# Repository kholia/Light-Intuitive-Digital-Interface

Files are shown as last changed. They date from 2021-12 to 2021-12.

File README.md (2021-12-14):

#### LiDi

LiDi is Light-Intuitive-Digital-Audio-Interface for µBITX and other radios. It
is meant to be homebrewed on a `Zero PCB` in under 30 minutes.

Design 2:

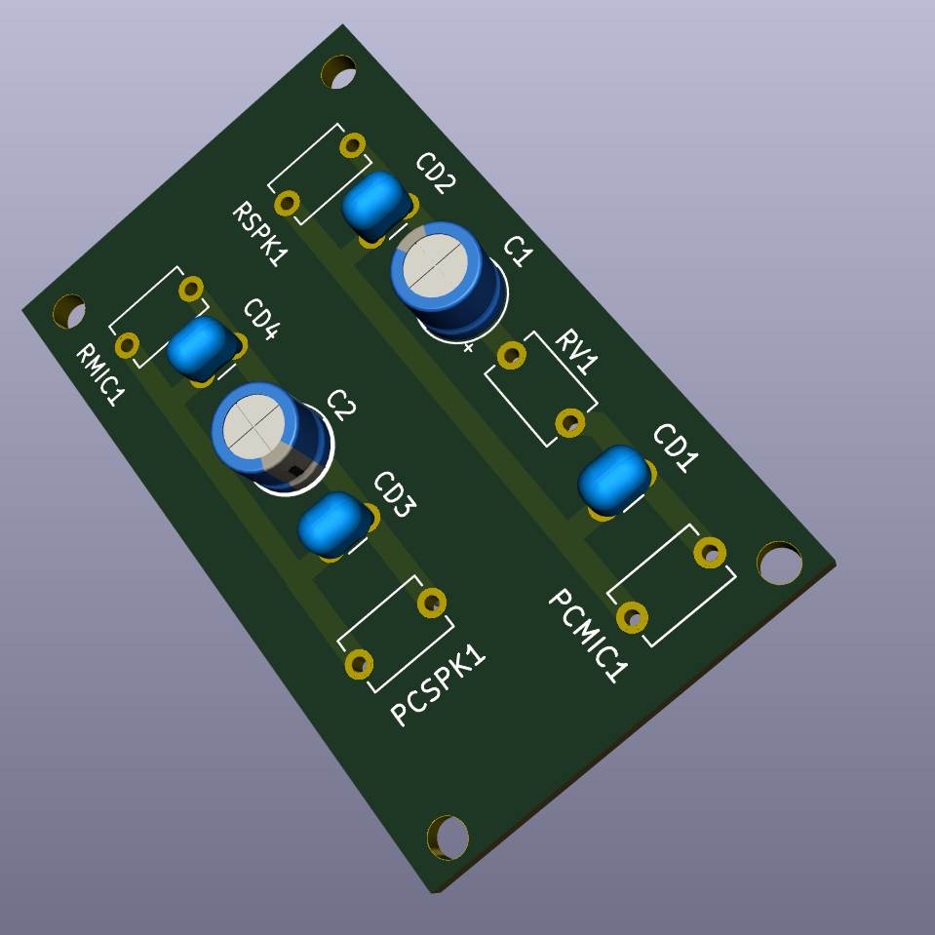
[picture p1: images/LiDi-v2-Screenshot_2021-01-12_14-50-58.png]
LiDi-v2

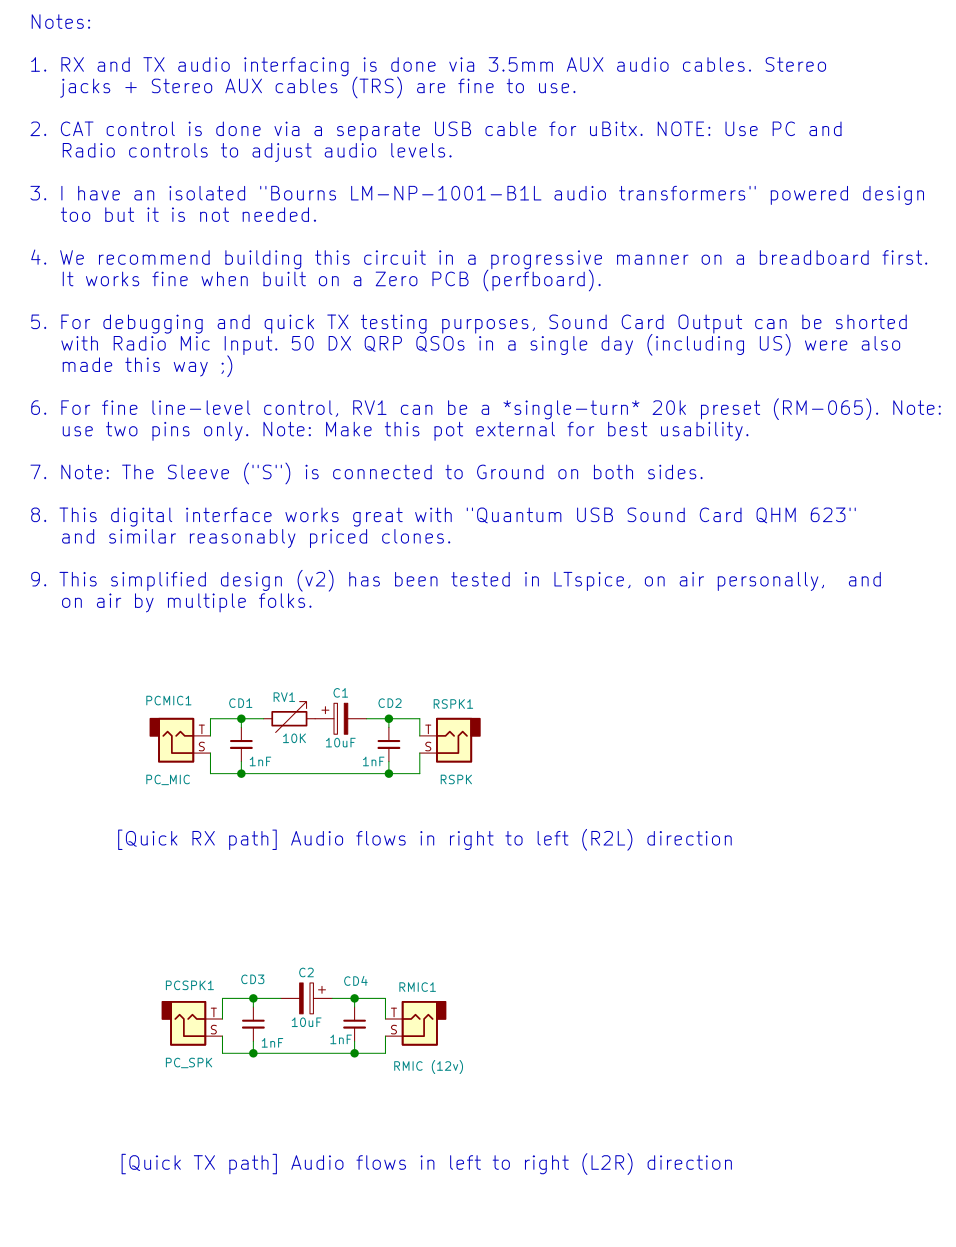
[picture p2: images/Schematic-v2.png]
LiDi-v2 Schematic


Design 1:

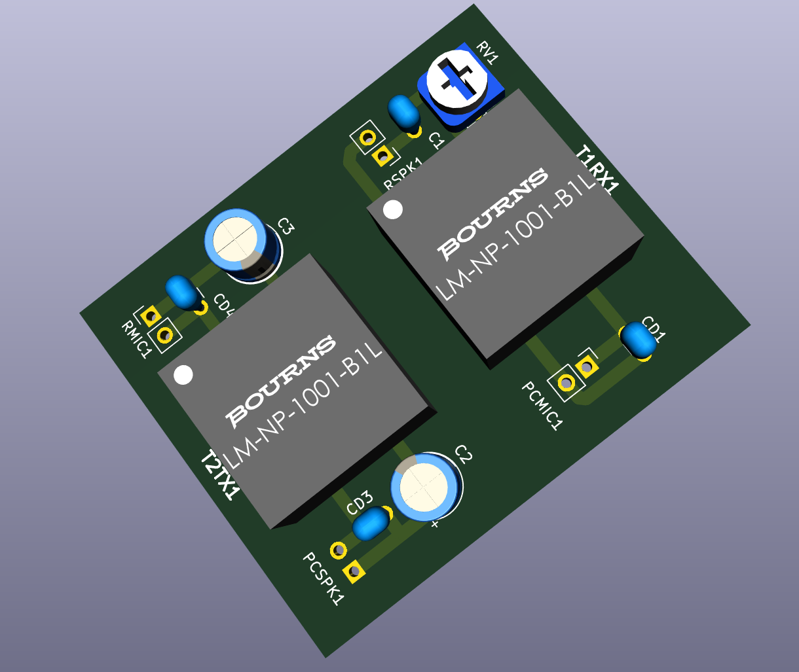
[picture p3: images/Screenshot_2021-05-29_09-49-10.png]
LiDi-v1


LiDi-v2

Full Setup 1

Note: All the included designs (and some other ones) were simulated in LTspice,
and then tested on air.

Sample testing setup on a breadboard ;)

PoC Setup 1

Sometimes, a quick shorted digital interface is all you need for a US QSO in
"Solar Minimum" conditions ;)

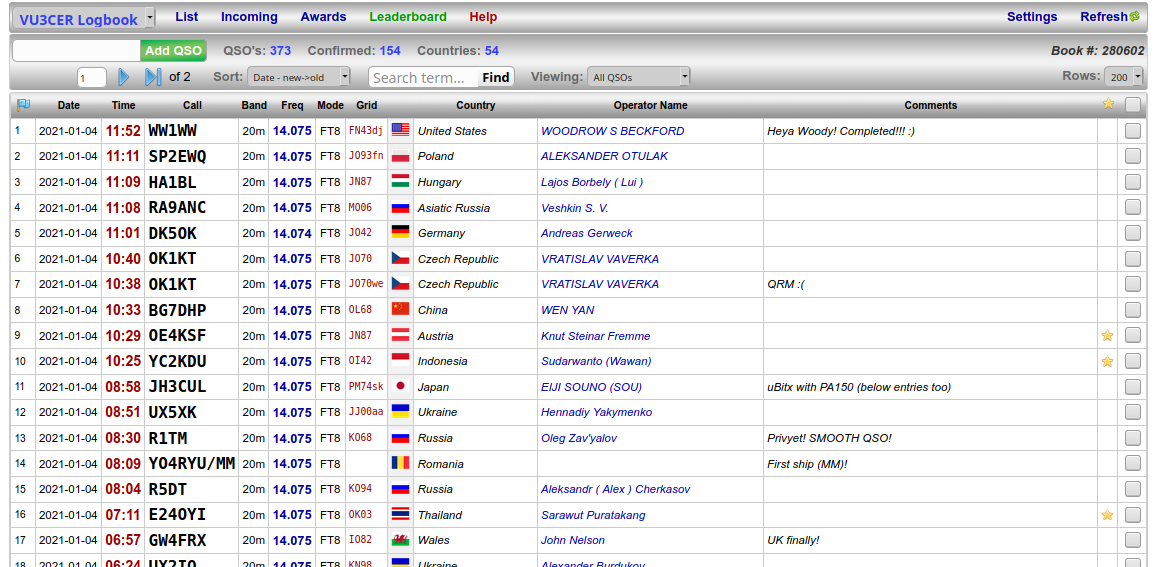
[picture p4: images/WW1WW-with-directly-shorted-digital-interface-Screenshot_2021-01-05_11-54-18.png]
Shorted-Digital-Interface


RX performance is lovely with LiDi - US @ -4.

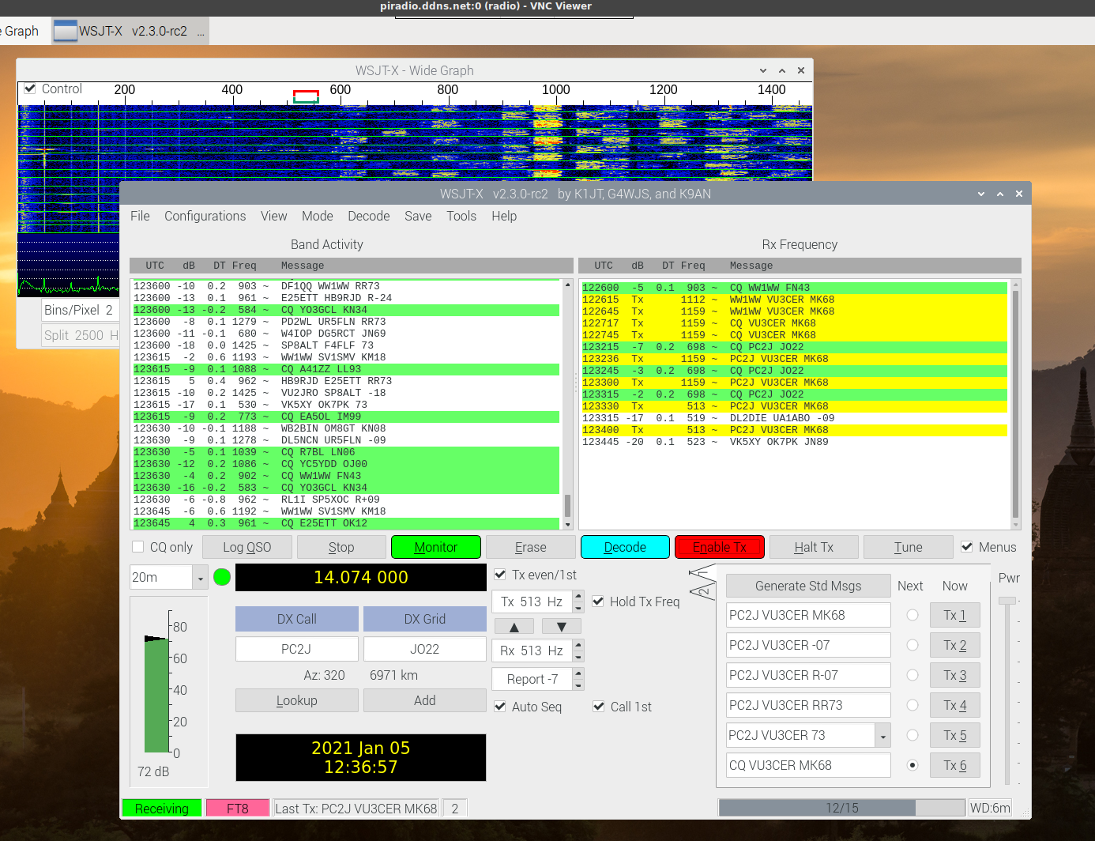
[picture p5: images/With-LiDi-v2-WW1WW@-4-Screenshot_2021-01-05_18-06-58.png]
US @ -4


50 QSOs were done with LiDi designs in a single day!

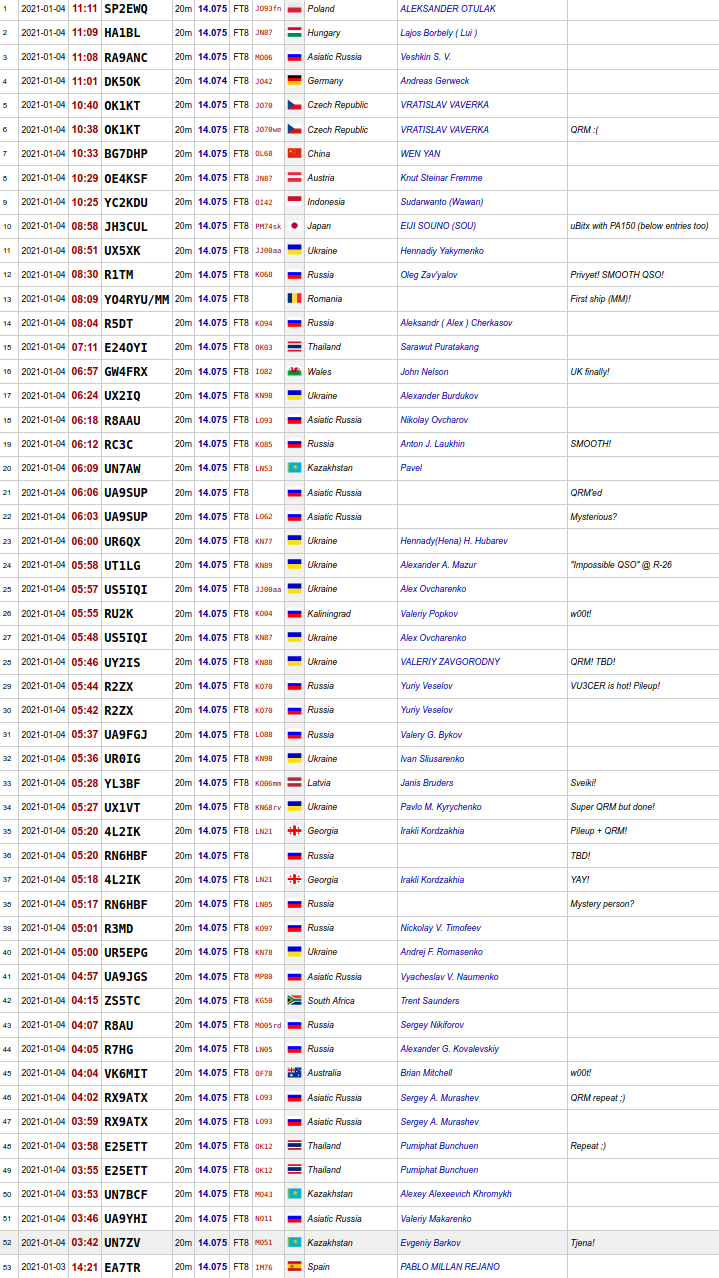
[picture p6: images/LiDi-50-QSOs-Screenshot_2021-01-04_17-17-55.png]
50 QSOs with LiDi


#### BOM Sources

- [Bourns LM-NP-1001-B1L 600:600 audio transformer](https://in.rsdelivers.com/product/bourns/lm-np-1001-b1l/chassis-mount-audio-transformer/1728110)

- [Bourns LM-NP-1001-B1L 600:600 audio transformer (alt source)](https://www.semikart.com/product/bourns-/LM-NP-1001-B1L/58614)

- [Audio & Signal isolation transformer 600:600 (alt source)](https://www.sunrom.com/p/audio-signal-isolation-transformer-600600)

- [GX-16 4-Pin Metal Aviation Plug Female](https://robu.in/product/gx-16-4-pin-metal-aviation-plug-male-and-female-panel-connector/)

- https://projectpoint.in/ (capacitors, pots, connectors)

- https://www.sunrom.com/ (audio connectors, caps, misc)

- https://www.electronicscomp.com/ (connectors, misc)

- https://www.electroncomponents.com/ (connectors, audio cables, misc)

- https://www.diyaudiocart.com/ (nice quality caps)

- [USB Sound Card](https://robu.in/product/5-1-channel-usb-sound-card-for-raspberry-pi-and-computers/)

#### µBITX Aviation Connector Pinout

Clockwise from the notch on the GX-16 connector:

Black + Blue -> Ground

Brown + "Red" -> Speaker

Anti-clockwise from the notch:

Purple -> Mic (TIP)

Orange -> PTT

Brown + "Red" -> Speaker

https://www.hfsignals.com/index.php/ubitx-wire-up/

https://source.android.com/devices/accessories/headset/plug-headset-spec

#### Tips

- Use KD8CEC firmware for µBITX. Use https://github.com/reedbn/ubitxv6 for
  µBITX v6.

- Configure WSJT-X for µBITX using details from the following article.

  http://www.hamskey.com/2018/01/wjst-x-configuration-for-ubitx.html

- For BITX40, use a suitable firmware from https://github.com/amunters.

  I have no experience with BITX40 though.

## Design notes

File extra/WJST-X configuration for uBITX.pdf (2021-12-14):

hamskey.com

## WJST-X configuration for uBITX

Share

2-3 minutes

WJST-X configuration for uBITX

Use CEC version firmware 2.5 or later of uBITX.
The following examples are based on version 0.27.
We will post the 0.27 version as the test ends.
All of the examples below only describe connections to uBITX. Please refer to the manual or other documents for how to use the program.

WJST-X
Download : https://physics.princeton.edu/pulsar/k1jt/wsjtx.html

After installing the program, connect the uBITX USB to the computer.

Run WSJT-X

Click File -> Settings...

WJST-X configuration for uBITX | about:reader?url=http://www.hamskey.com/2018/01/wj...
1 of 6 | 5/29/21, 10:24

Select Yaesu FT-817 from the Rig selection menu.

Select the serial port to which uBITX is connected.

When uBITX is connected to the USB port of the computer, the virtual serial port appears in the control panel.

The baud rate is set to 38400.

PTT Method selects CAT.

Please make other settings as shown below.

Then press the Test CAT button.
Maybe there is a timeout error.
Raduino (problem of Arduino) has the problem that it is automatically reset when first serial port is connected after power is supplied.
I've posted a troubleshooting article on my blog. If you want to solve it, please read it.

But I just use it. There will be no problem after that.

Press the Test PTT Button

Then, Your uBITX should be changed to TX mode as shown below.

Press the OK button.

The frequency of the main screen of wsjt-x may be changed automatically.
I selected the JT-65 mode and the frequency was automatically changed to 14.076.000.

Now you can have a happy ham life with wsjt-x and uBITX.

If you select a band on wsjt-x, your uBITX will automatically change its frequency and mode.
It is important. If only PTT is connected without frequency synchronization, wsjt-x may be recorded as an incorrect band when it records the log automatically.

The photo below was taken directly from this document.

The settings in the raspberry pie are the same.
The video below is a video that I tested on Windows and Raspberry.

73

Ian KD8CEC

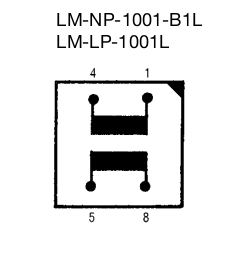
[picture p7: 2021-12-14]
images/Bourns Audio Transformer Pinout (BOTTOM VIEW IMPORTANT).png

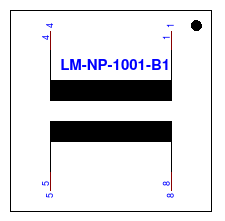
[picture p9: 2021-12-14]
images/Bourns Audio Transformer Pinout (BOTTOM VIEW IMPORTANT) 2.png

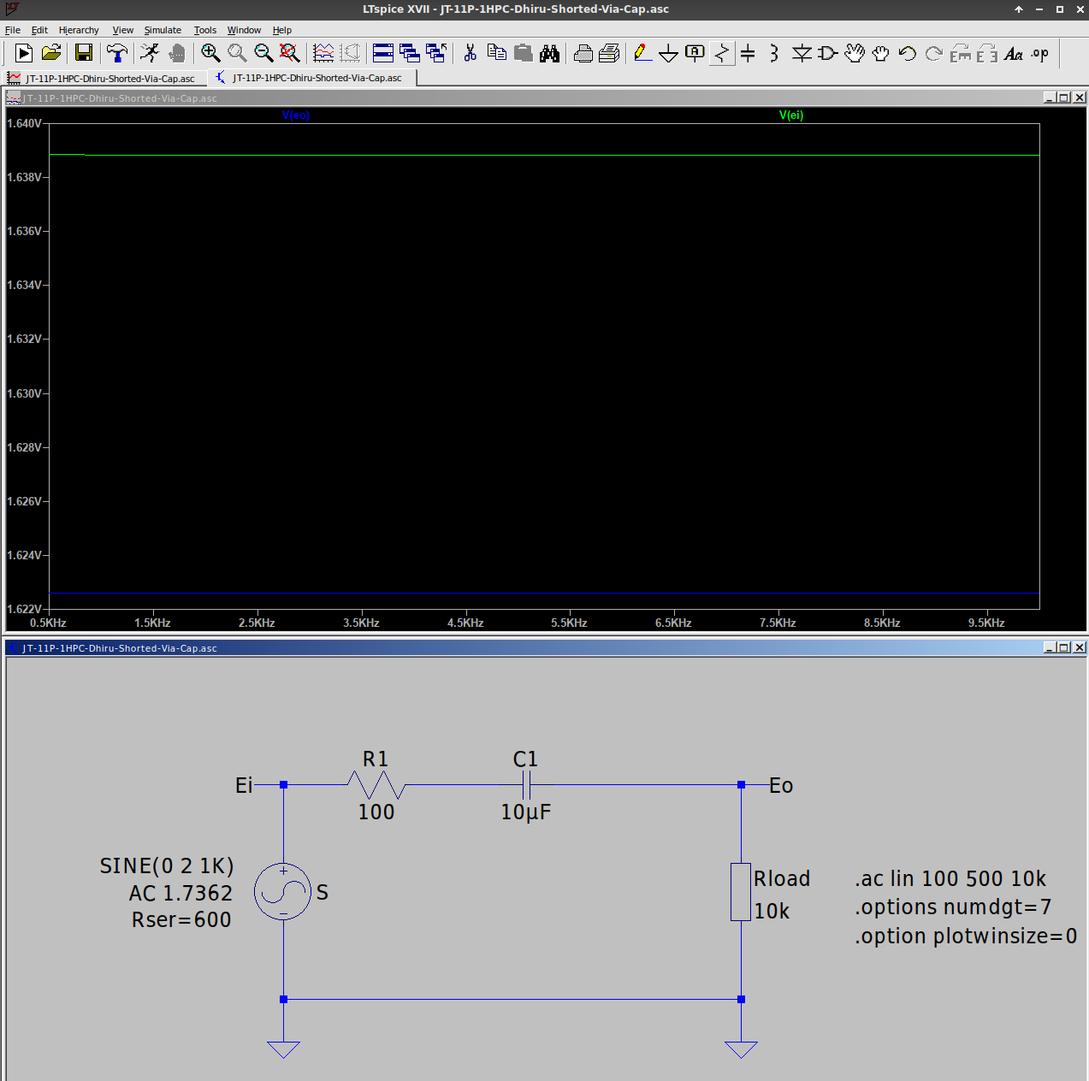
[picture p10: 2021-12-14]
LiDi-Simulation/DuinoVOX + Dhiru Design - Screenshot_2021-01-05_11-32-19.png

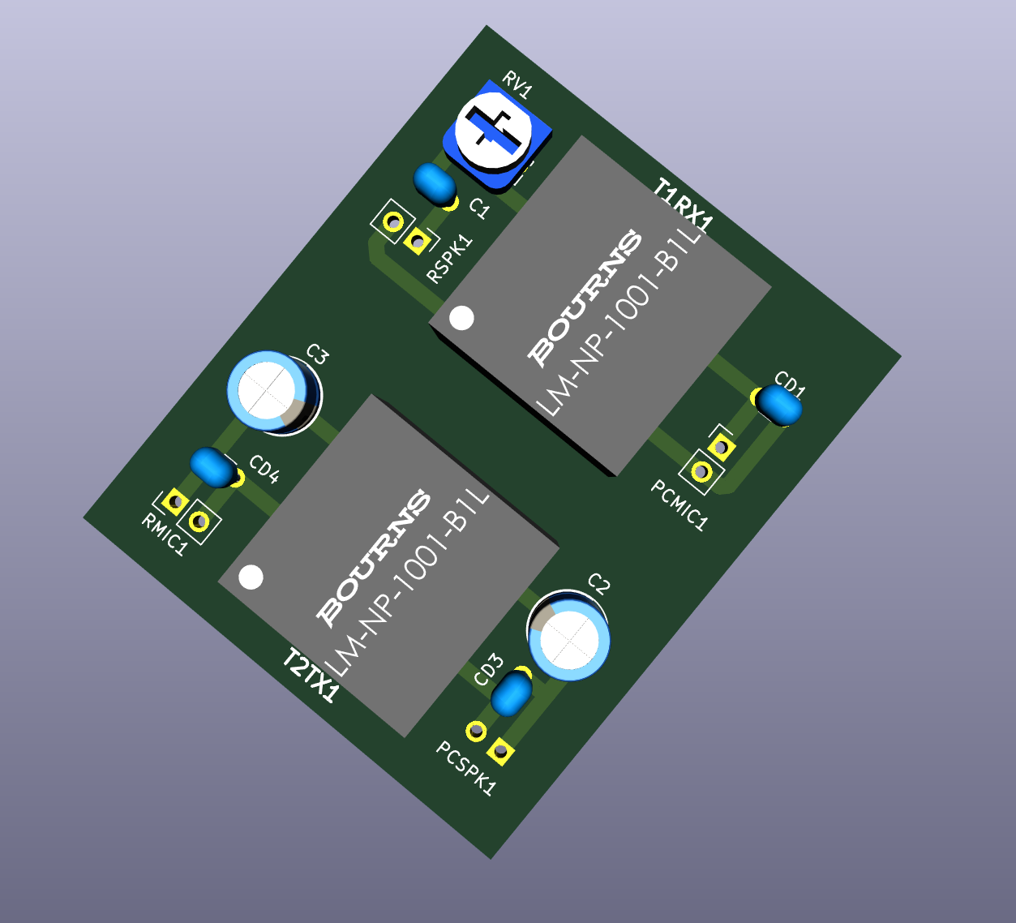
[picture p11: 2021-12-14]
images/LiDi v1 - Screenshot_2020-12-27_16-06-44.png

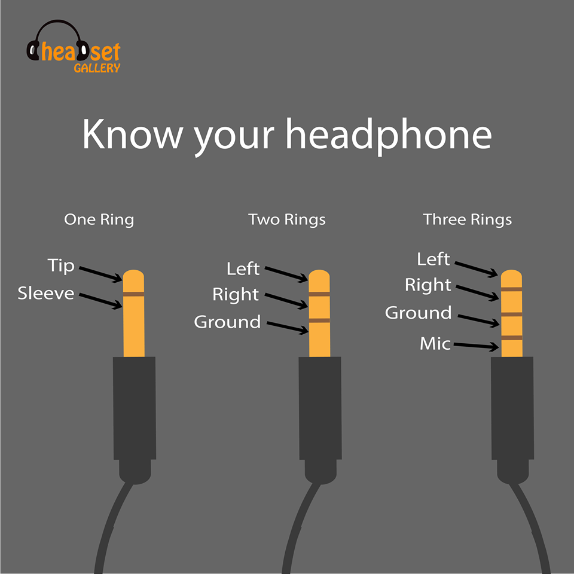
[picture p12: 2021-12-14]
images/3acbfe1cbb91678875ff1e402110526c.png

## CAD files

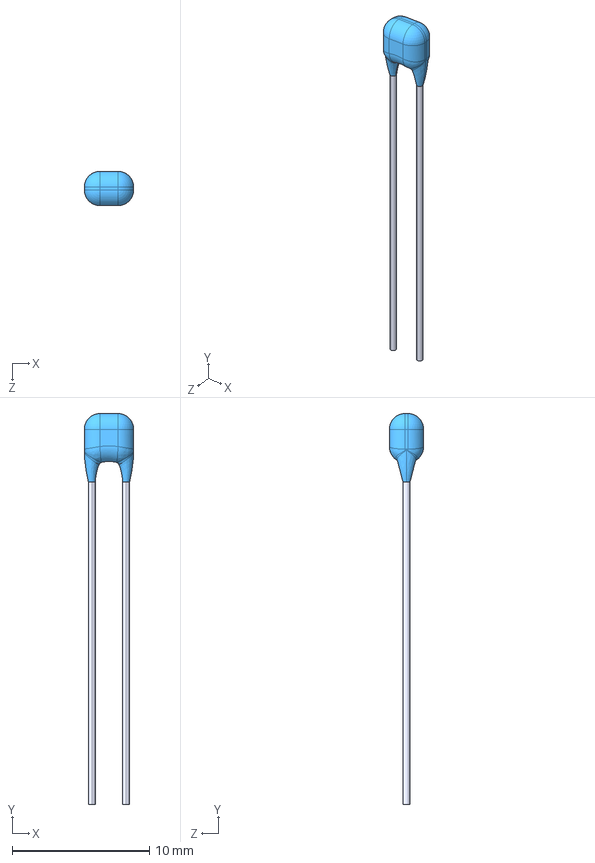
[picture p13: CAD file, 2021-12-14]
LiDi-v2/models/RCE5C1H6R0D0DBH03A.STEP
3.60 x 28.5 x 2.50 mm

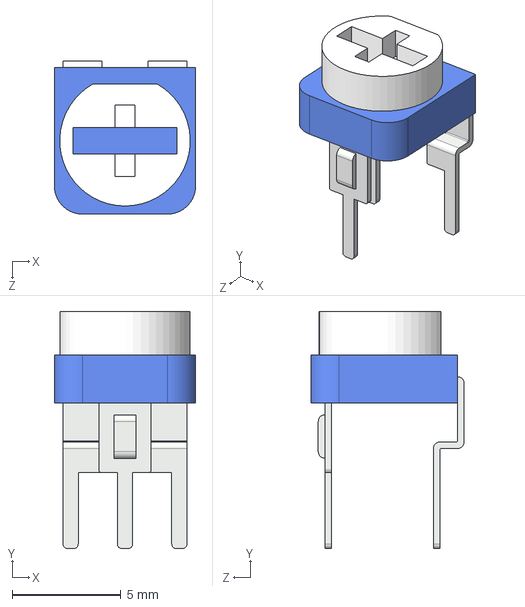
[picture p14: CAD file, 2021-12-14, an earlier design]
LiDi-v1/models/Pot - RES_VAR1.STEP
6.50 x 10.9 x 7.05 mm

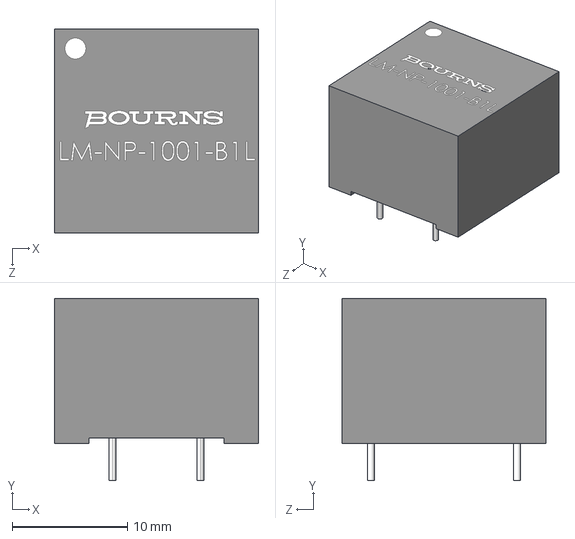
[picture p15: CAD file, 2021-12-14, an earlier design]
LiDi-v1/models/LM-NP-1001-B1L.STP
17.7 x 15.8 x 17.7 mm

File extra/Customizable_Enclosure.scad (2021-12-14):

enclosure_inner_length = 70;
enclosure_inner_width = 70;
enclosure_inner_depth = 30;

enclosure_thickness = 3;

cover_thickness = 3;

part = "cover"; // [enclosure:Enclosure, cover:Cover, both:Enclosure and Cover]

print_part();

module print_part() {
	if (part == "enclosure") {
		box2(enclosure_inner_length,enclosure_inner_width,enclosure_inner_depth,enclosure_thickness,enclosure_thickness/2-0.10,cover_thickness);
	} else if (part == "cover") {
		lid2(enclosure_inner_length,enclosure_inner_width,enclosure_inner_depth,enclosure_thickness,enclosure_thickness/2+0.10,cover_thickness);
	} else {
		both();
	}
}

module both() {

box2(enclosure_inner_length,enclosure_inner_width,enclosure_inner_depth,enclosure_thickness,enclosure_thickness/2-0.10,cover_thickness);
lid2(enclosure_inner_length,enclosure_inner_width,enclosure_inner_depth,enclosure_thickness,enclosure_thickness/2+0.10,cover_thickness);

}

module screws(in_x, in_y, in_z, shell) {

	sx = in_x/2 - 4;
	sy = in_y/2 - 4;
	sh = shell + in_z - 12;
	nh = shell + in_z - 4;

translate([0,0,0]) {
	translate([sx , sy, sh]) cylinder(r=1.5, h = 15, $fn=32);
	translate([sx , -sy, sh ]) cylinder(r=1.5, h = 15, $fn=32);
	translate([-sx , sy, sh ]) cylinder(r=1.5, h = 15, $fn=32);
	translate([-sx , -sy, sh ]) cylinder(r=1.5, h = 15, $fn=32);


	translate([-sx , -sy, nh ]) rotate([0,0,-45])
		translate([-5.75/2, -5.6/2, -0.7]) cube ([5.75, 10, 2.8]);
	translate([sx , -sy, nh ]) rotate([0,0,45])
		translate([-5.75/2, -5.6/2, -0.7]) cube ([5.75, 10, 2.8]);
	translate([sx , sy, nh ]) rotate([0,0,90+45])
		translate([-5.75/2, -5.6/2, -0.7]) cube ([5.75, 10, 2.8]);
	translate([-sx , sy, nh ]) rotate([0,0,-90-45])
		translate([-5.75/2, -5.6/2, -0.7]) cube ([5.75, 10, 2.8]);
}
}

module bottom(in_x, in_y, in_z, shell) {

	hull() {
   	 	translate([-in_x/2+shell, -in_y/2+shell, 0]) cylinder(r=shell*2,h=shell, $fn=32);
		translate([+in_x/2-shell, -in_y/2+shell, 0]) cylinder(r=shell*2,h=shell, $fn=32);
		translate([+in_x/2-shell, in_y/2-shell, 0]) cylinder(r=shell*2,h=shell, $fn=32);
		translate([-in_x/2+shell, in_y/2-shell, 0]) cylinder(r=shell*2,h=shell, $fn=32);
	}
}

module sides(in_x, in_y, in_z, shell) {
translate([0,0,shell])
difference() {

	hull() {
   	 	translate([-in_x/2+shell, -in_y/2+shell, 0]) cylinder(r=shell*2,h=in_z, $fn=32);
		translate([+in_x/2-shell, -in_y/2+shell, 0]) cylinder(r=shell*2,h=in_z, $fn=32);
		translate([+in_x/2-shell, in_y/2-shell, 0]) cylinder(r=shell*2,h=in_z, $fn=32);
		translate([-in_x/2+shell, in_y/2-shell, 0]) cylinder(r=shell*2,h=in_z, $fn=32);
	}

	hull() {
   	 	translate([-in_x/2+shell, -in_y/2+shell, 0]) cylinder(r=shell,h=in_z+1, $fn=32);
		translate([+in_x/2-shell, -in_y/2+shell, 0]) cylinder(r=shell,h=in_z+1, $fn=32);
		translate([+in_x/2-shell, in_y/2-shell, 0]) cylinder(r=shell,h=in_z+1, $fn=32);
		translate([-in_x/2+shell, in_y/2-shell, 0]) cylinder(r=shell,h=in_z+1, $fn=32);
	}
}

intersection() {
	translate([-in_x/2, -in_y/2, shell]) cube([in_x, in_y, in_z+2]);

	union() {
	translate([-in_x/2 , -in_y/2,shell + in_z -6]) cylinder(r=9, h = 6, $fn=64);
	translate([-in_x/2 , -in_y/2,shell + in_z -10]) cylinder(r1=3, r2=9, h = 4, $fn=64);

	translate([in_x/2 , -in_y/2, shell + in_z -6]) cylinder(r=9, h = 6, $fn=64);
	translate([in_x/2 , -in_y/2, shell + in_z -10]) cylinder(r1=3, r2=9, h = 4, $fn=64);

	translate([in_x/2 , in_y/2,  shell + in_z -6]) cylinder(r=9, h = 6, $fn=64);
	translate([in_x/2 , in_y/2,  shell + in_z -10]) cylinder(r1=3, r2=9, h = 4, $fn=64);

	translate([-in_x/2 , in_y/2, shell + in_z -6]) cylinder(r=9, h = 6, $fn=64);
	translate([-in_x/2 , in_y/2, shell + in_z -10]) cylinder(r1=3, r2=9, h = 4, $fn=64);
	}

}
}

module lid_top_lip2(in_x, in_y, in_z, shell, top_lip, top_thickness) {

	cxm = -in_x/2 - (shell-top_lip);
	cxp = in_x/2 + (shell-top_lip);
	cym = -in_y/2 - (shell-top_lip);
	cyp = in_y/2 + (shell-top_lip);

	translate([0,0,shell+in_z])

difference() {

	hull() {
   	 	translate([-in_x/2+shell, -in_y/2+shell, 0]) cylinder(r=shell*2,h=top_thickness, $fn=32);
		translate([+in_x/2-shell, -in_y/2+shell, 0]) cylinder(r=shell*2,h=top_thickness, $fn=32);
		translate([+in_x/2-shell, in_y/2-shell, 0]) cylinder(r=shell*2,h=top_thickness, $fn=32);
		translate([-in_x/2+shell, in_y/2-shell, 0]) cylinder(r=shell*2,h=top_thickness, $fn=32);
	}


	translate([0, 0, -1]) linear_extrude(height = top_thickness + 2) polygon(points = [
		[cxm+5, cym],
		[cxm, cym+5],
		[cxm, cyp-5],
		[cxm+5, cyp],
		[cxp-5, cyp],
		[cxp, cyp-5],
		[cxp, cym+5],
		[cxp-5, cym]]);
}
}

module lid2(in_x, in_y, in_z, shell, top_lip, top_thickness) {

	cxm = -in_x/2 - (shell-top_lip);
	cxp = in_x/2 + (shell-top_lip);
	cym = -in_y/2 - (shell-top_lip);
	cyp = in_y/2 + (shell-top_lip);

difference() {
	translate([0, 0, in_z+shell]) linear_extrude(height = top_thickness ) polygon(points = [
		[cxm+5, cym],
		[cxm, cym+5],
		[cxm, cyp-5],
		[cxm+5, cyp],
		[cxp-5, cyp],
		[cxp, cyp-5],
		[cxp, cym+5],
		[cxp-5, cym]]);


		screws(in_x, in_y, in_z, shell);


}
}

module box2(in_x, in_y, in_z, shell, top_lip, top_thickness) {
	bottom(in_x, in_y, in_z, shell);
	difference() {
		sides(in_x, in_y, in_z, shell);
		screws(in_x, in_y, in_z, shell);
	}
	lid_top_lip2(in_x, in_y, in_z, shell, top_lip, top_thickness);
}

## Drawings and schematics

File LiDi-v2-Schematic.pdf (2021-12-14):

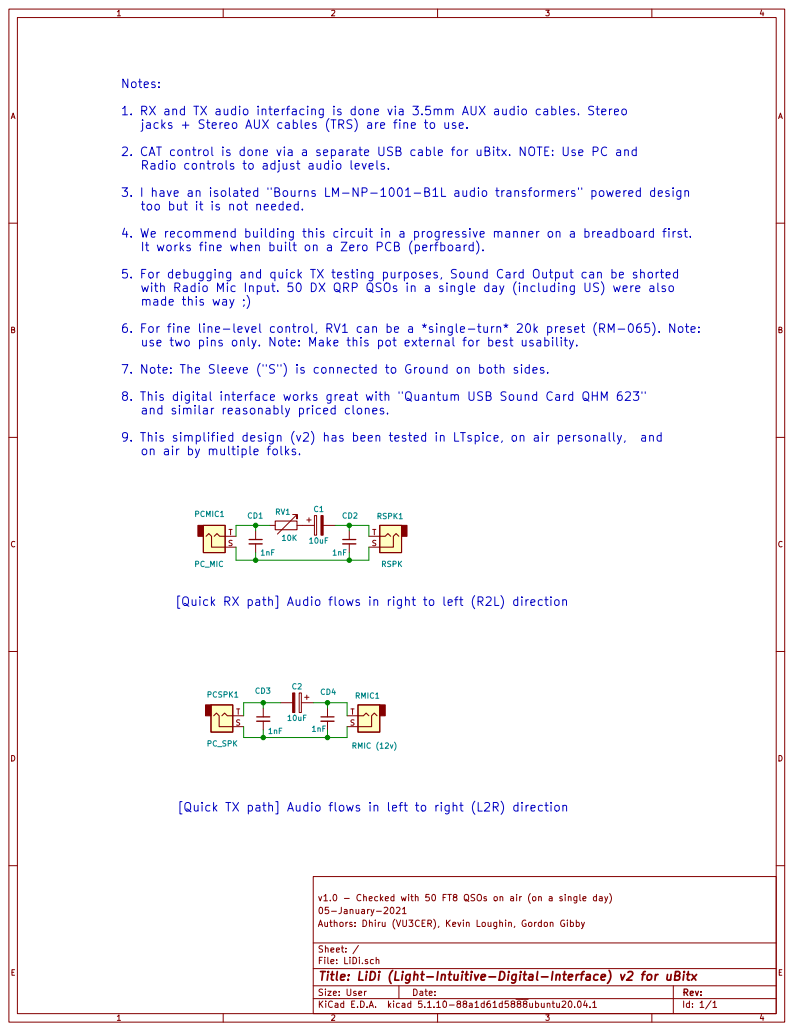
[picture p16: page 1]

Notes:
1. RX and TX audio interfacing is done via 3.5mm AUX audio cables. Stereo
jacks + Stereo AUX cables (TRS) are fine to use.
2. CAT control is done via a separate USB cable for uBitx. NOTE: Use PC and
Radio controls to adjust audio levels.
3. I have an isolated "Bourns LM-NP-1001-B1L audio transformers" powered design
too but it is not needed.
4. We recommend building this circuit in a progressive manner on a breadboard first.
It works fine when built on a Zero PCB (perfboard).
5. For debugging and quick TX testing purposes, Sound Card Output can be shorted
with Radio Mic Input. 50 DX QRP QSOs in a single day (including US) were also
made this way ;)
6. For fine line-level control, RV1 can be a *single-turn* 20k preset (RM-065). Note:
use two pins only. Note: Make this pot external for best usability.
7. Note: The Sleeve ("S") is connected to Ground on both sides.
8. This digital interface works great with "Quantum USB Sound Card QHM 623"
and similar reasonably priced clones.
9. This simplified design (v2) has been tested in LTspice, on air personally, and
on air by multiple folks.
TRMIC1 RMIC (12v) C1
10uFCD4

[Quick RX path] Audio flows in right to left (R2L) direction

[Quick TX path] Audio flows in left to right (L2R) direction

v1.0 - Checked with 50 FT8 QSOs on air (on a single day)
05-January-2021
File: LiDi.sch Sheet: / Authors: Dhiru (VU3CER), Kevin Loughin, Gordon Gibby

Id: 1/1 Title: LiDi (Light-Intuitive-Digital-Interface) v2 for uBitx

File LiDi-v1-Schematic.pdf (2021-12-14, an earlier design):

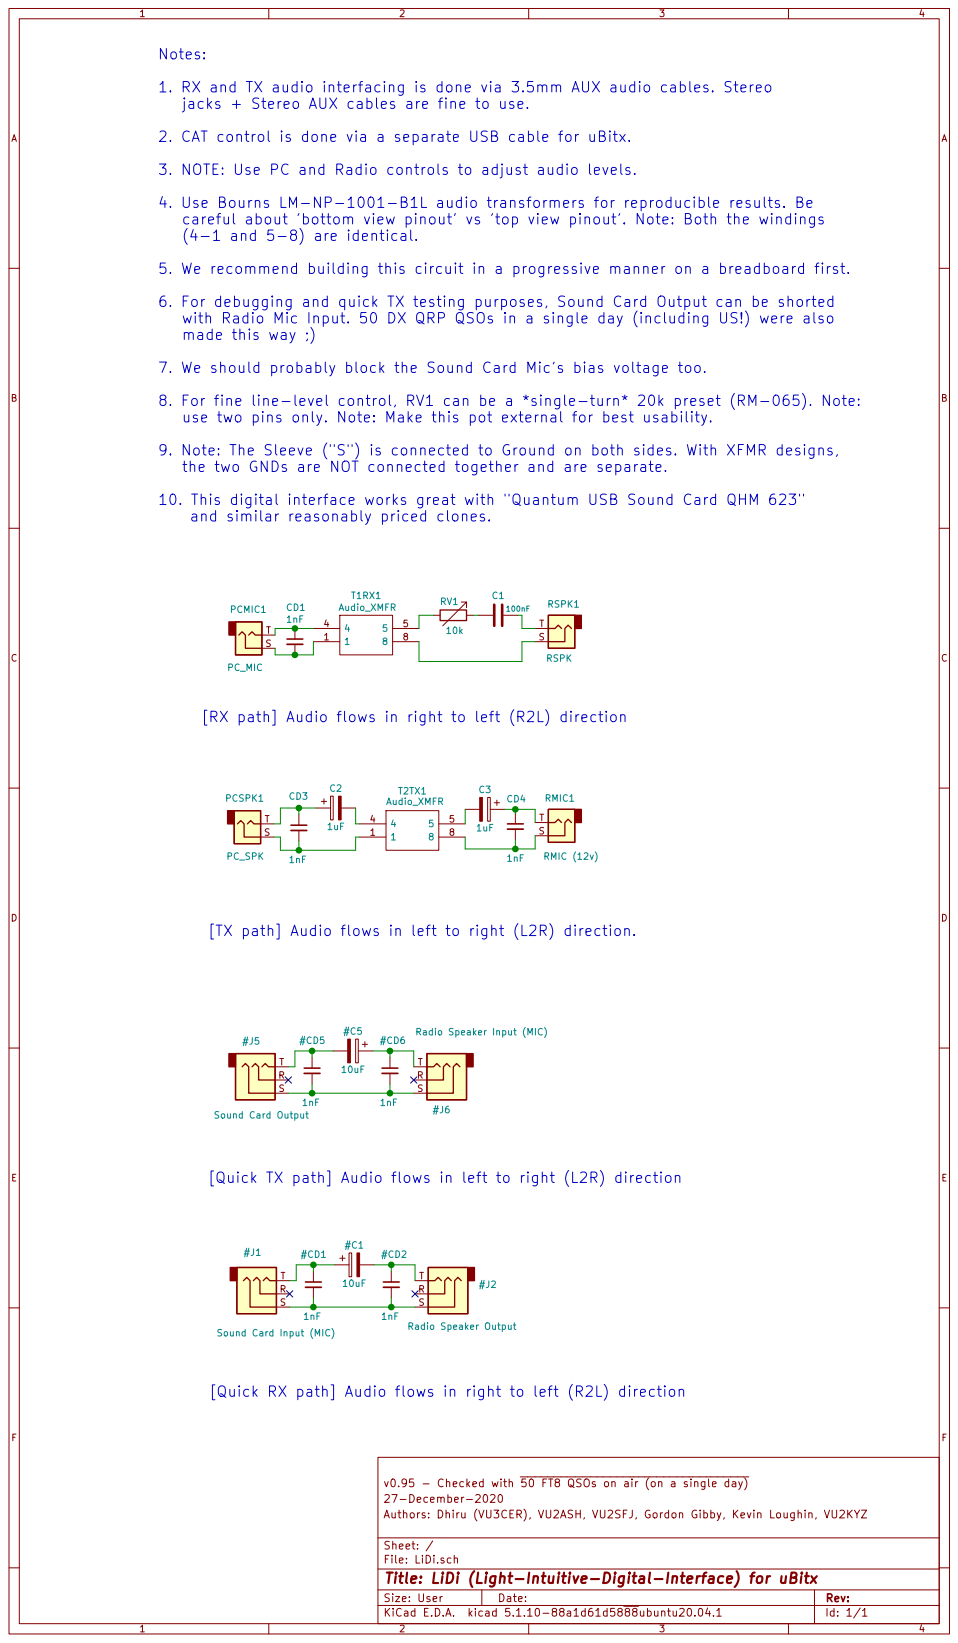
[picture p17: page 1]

Notes:
1. RX and TX audio interfacing is done via 3.5mm AUX audio cables. Stereo
jacks + Stereo AUX cables are fine to use.
2. CAT control is done via a separate USB cable for uBitx.
3. NOTE: Use PC and Radio controls to adjust audio levels.
4. Use Bourns LM-NP-1001-B1L audio transformers for reproducible results. Be
careful about 'bottom view pinout' vs 'top view pinout'. Note: Both the windings
(4-1 and 5-8) are identical.
5. We recommend building this circuit in a progressive manner on a breadboard first.
6. For debugging and quick TX testing purposes, Sound Card Output can be shorted
with Radio Mic Input. 50 DX QRP QSOs in a single day (including US!) were also
made this way ;)
7. We should probably block the Sound Card Mic's bias voltage too.
8. For fine line-level control, RV1 can be a *single-turn* 20k preset (RM-065). Note:
use two pins only. Note: Make this pot external for best usability.
9. Note: The Sleeve ("S") is connected to Ground on both sides. With XFMR designs,
the two GNDs are NOT connected together and are separate.
10. This digital interface works great with "Quantum USB Sound Card QHM 623"
and similar reasonably priced clones.

#J6 Radio Speaker Input (MIC) S

[RX path] Audio flows in right to left (R2L) direction

[TX path] Audio flows in left to right (L2R) direction.

[Quick TX path] Audio flows in left to right (L2R) direction

[Quick RX path] Audio flows in right to left (R2L) direction

v0.95 - Checked with 50 FT8 QSOs on air (on a single day)
27-December-2020
File: LiDi.sch Sheet: / Authors: Dhiru (VU3CER), VU2ASH, VU2SFJ, Gordon Gibby, Kevin Loughin, VU2KYZ

Id: 1/1 Title: LiDi (Light-Intuitive-Digital-Interface) for uBitx

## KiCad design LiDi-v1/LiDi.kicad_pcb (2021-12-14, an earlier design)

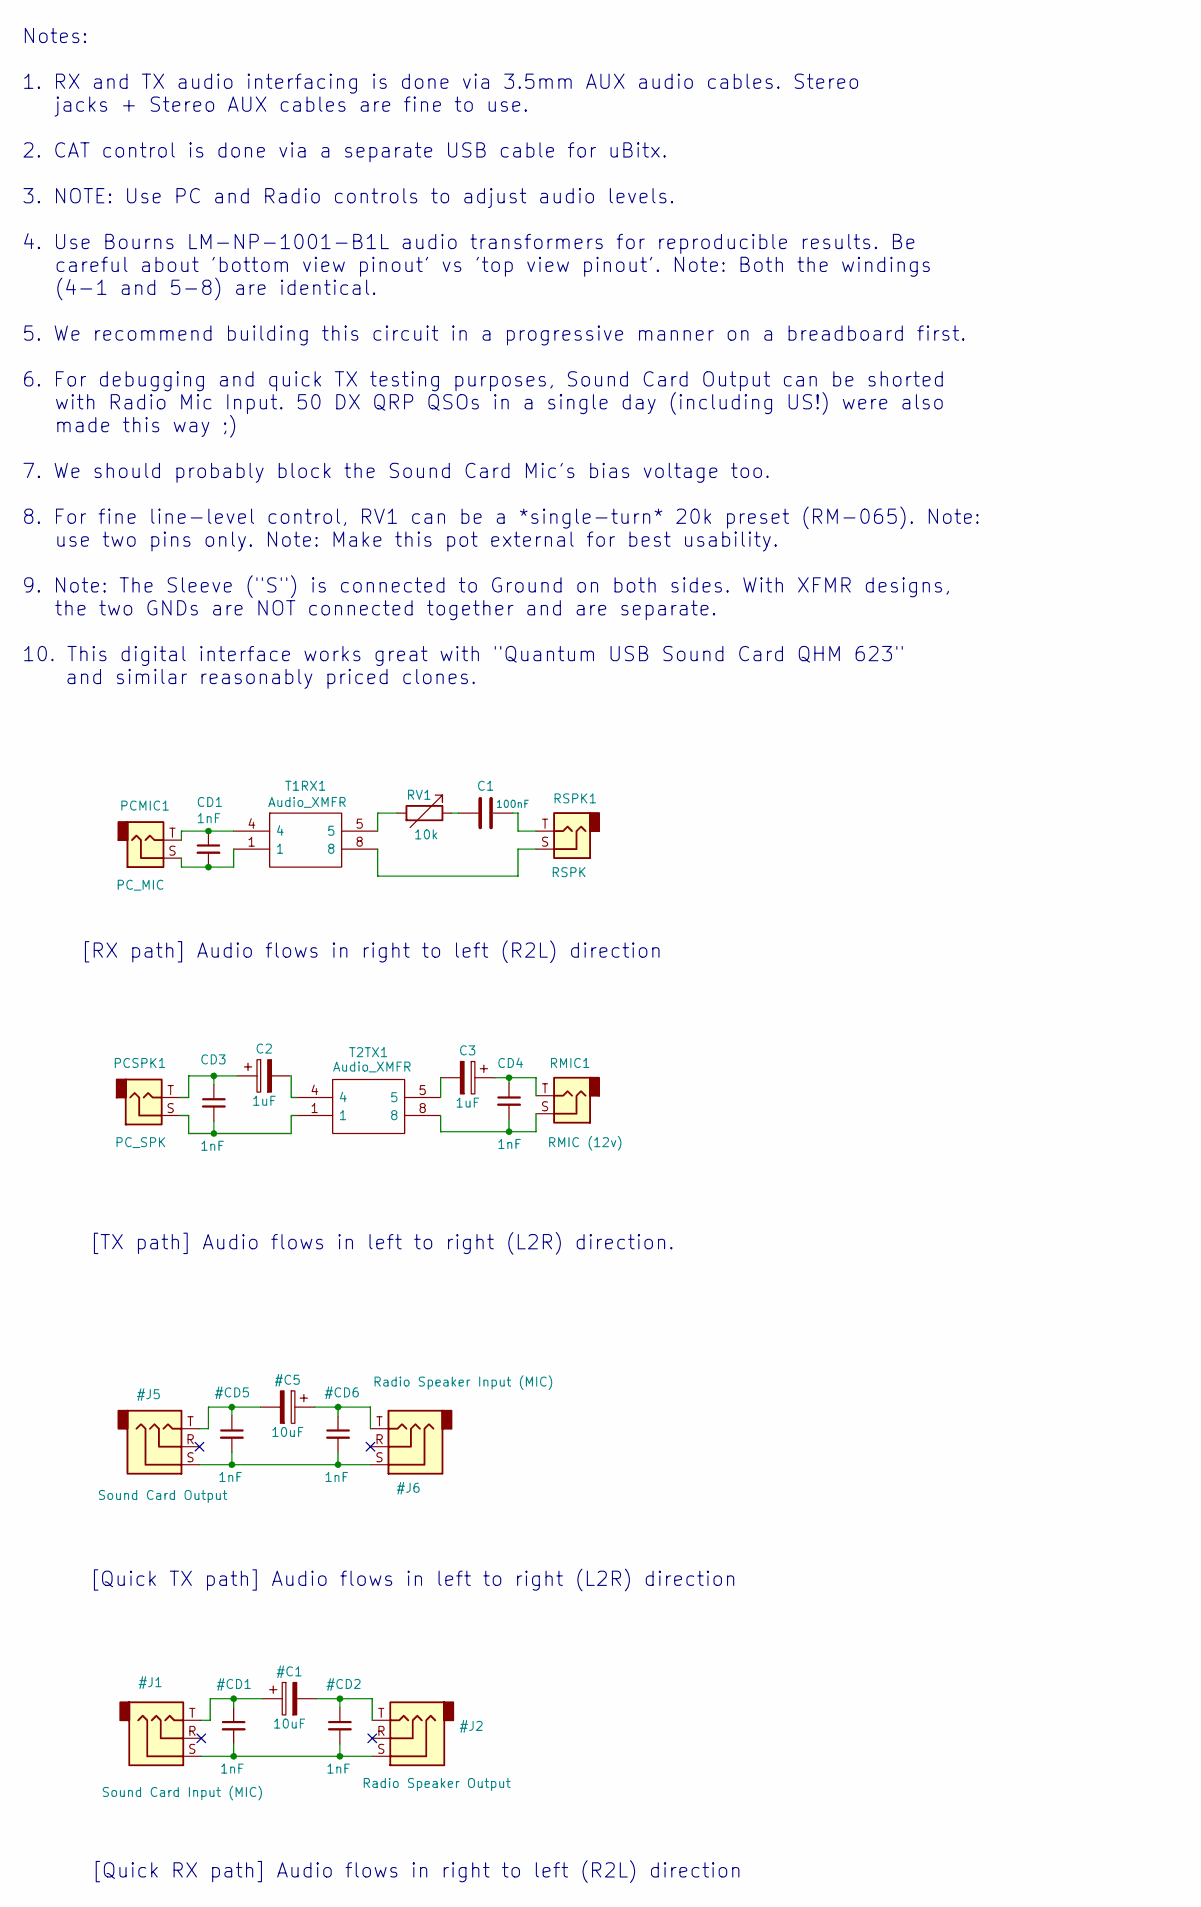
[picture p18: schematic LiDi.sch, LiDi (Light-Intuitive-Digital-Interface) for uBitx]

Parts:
C1: 100nF; C_Disc_D3.0mm_W1.6mm_P2.50mm
C2, C3: 1uF; CP_Radial_D6.3mm_P2.50mm
CD1, CD3, CD4: 1nF; C_Disc_D3.0mm_W1.6mm_P2.50mm
PCMIC1: PC_MIC; Custom_PinHeader_1x02_P2.54mm_Vertical
PCSPK1: PC_SPK; Custom_PinHeader_1x02_P2.54mm_Vertical
RMIC1: RMIC (12v); Custom_PinHeader_1x02_P2.54mm_Vertical
RSPK1: RSPK; Custom_PinHeader_1x02_P2.54mm_Vertical
RV1: 10k; Potentiometer_Runtron_RM-063_Horizontal
T1RX1, T2TX1: Audio_XMFR; LMNP1001B1L; Manufacturer_Part_Number LM-NP-1001-B1L; Mouser Part Number 652-LM-NP-1001-B1L

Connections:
unnamed: C1.1, RSPK1.T
unnamed: C1.2, RV1.1
unnamed: C2.1, CD3.1, PCSPK1.T
unnamed: C2.2, T2TX1.4
unnamed: C3.1, CD4.1, RMIC1.T
unnamed: C3.2, T2TX1.5
unnamed: CD1.1, PCMIC1.T, T1RX1.4
unnamed: CD1.2, PCMIC1.S, T1RX1.1
unnamed: CD3.2, PCSPK1.S, T2TX1.1
unnamed: CD4.2, RMIC1.S, T2TX1.8
unnamed: RSPK1.S, T1RX1.8
unnamed: RV1.2, T1RX1.5

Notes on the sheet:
[RX path] Audio flows in right to left (R2L) direction
[TX path] Audio flows in left to right (L2R) direction.
Notes: 1. RX and TX audio interfacing is done via 3.5mm AUX audio cables. Stereo jacks + Stereo AUX cables are fine to use. 2. CAT control is done via a separate USB cable for uBitx. 3. NOTE: Use PC and Radio controls to adjust audio levels. 4. Use Bourns LM-NP-1001-B1L audio transformers for repro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
[Quick TX path] Audio flows in left to right (L2R) direction
[Quick RX path] Audio flows in right to left (R2L) direction

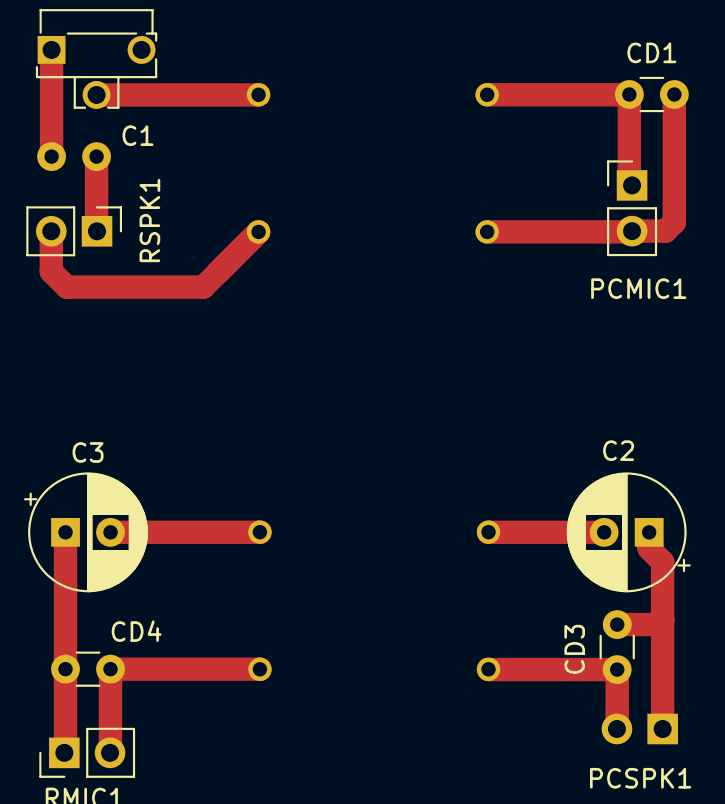
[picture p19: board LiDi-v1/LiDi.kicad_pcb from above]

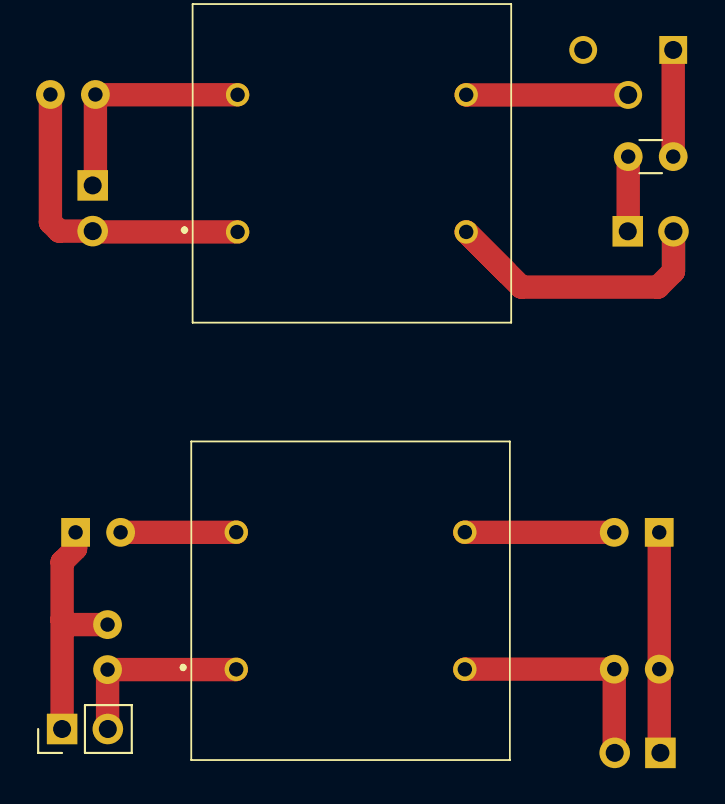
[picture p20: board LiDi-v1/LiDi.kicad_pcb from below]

Board: 2 copper layers, 13 parts (4 on the bottom side), 12 nets.

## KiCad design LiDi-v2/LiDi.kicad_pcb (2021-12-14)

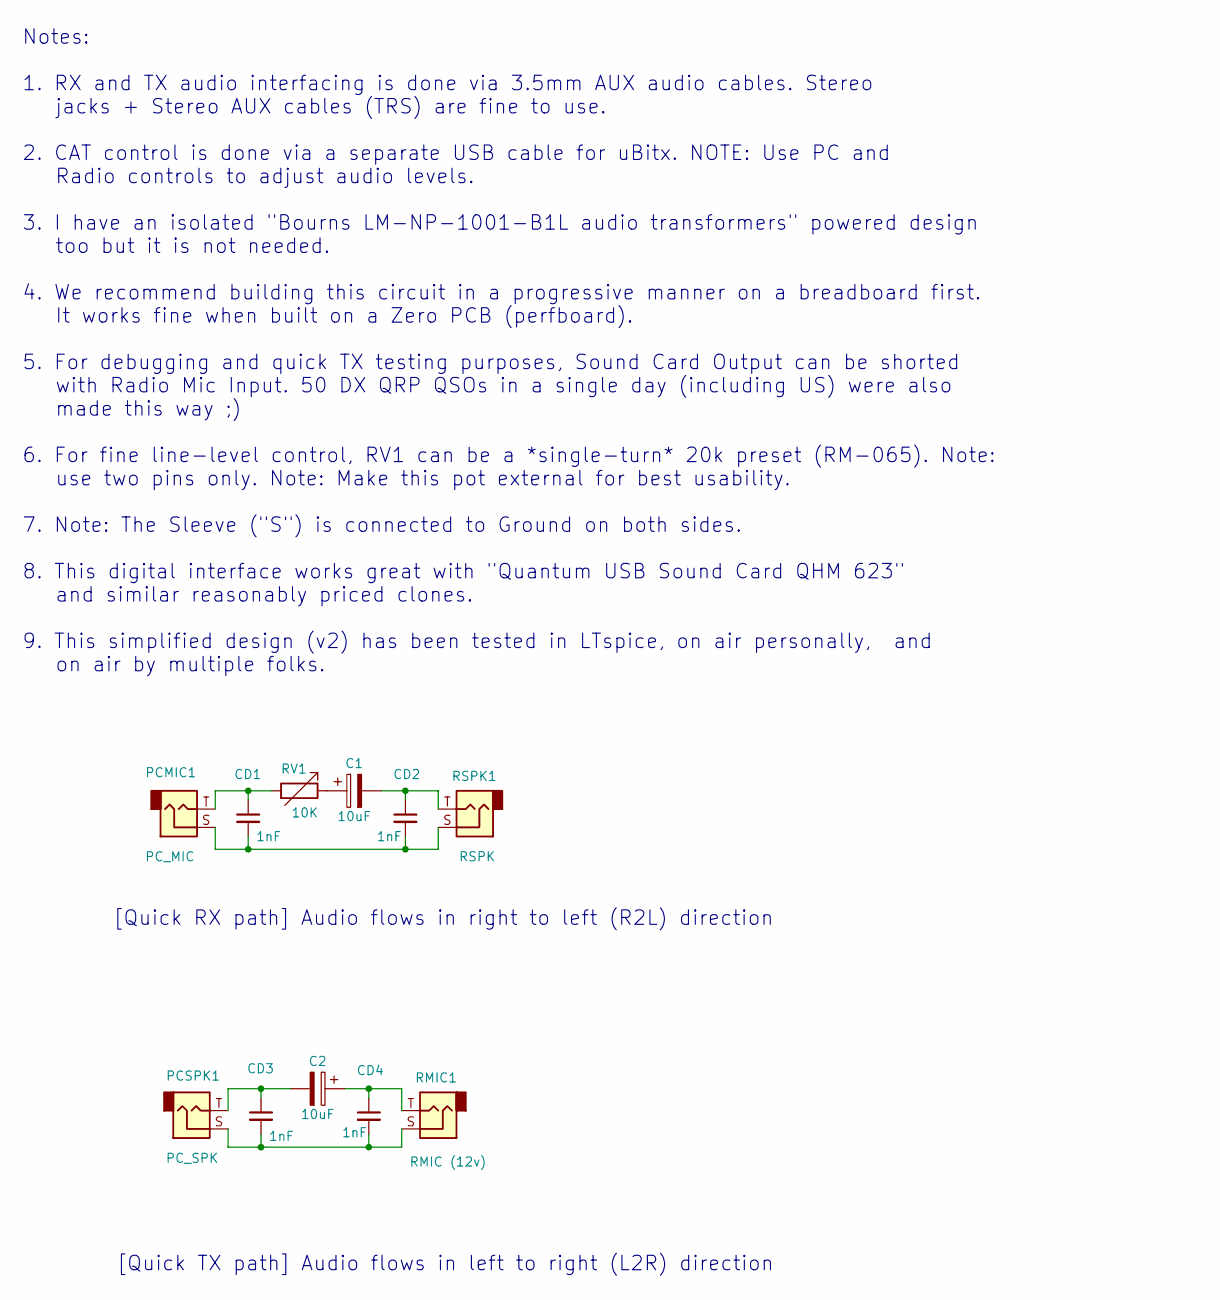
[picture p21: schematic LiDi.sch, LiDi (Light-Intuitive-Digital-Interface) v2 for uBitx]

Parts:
C1, C2: 10uF; CP_Radial_D5.0mm_P2.50mm
CD1, CD2, CD3, CD4: 1nF; C_Disc_D3.0mm_W1.6mm_P2.50mm
PCMIC1: PC_MIC; C_Disc_D5.1mm_W3.2mm_P5.00mm
PCSPK1: PC_SPK; C_Disc_D5.1mm_W3.2mm_P5.00mm
RMIC1: RMIC (12v); C_Disc_D5.1mm_W3.2mm_P5.00mm
RSPK1: RSPK; C_Disc_D5.1mm_W3.2mm_P5.00mm
RV1: 10K; 12_C_Disc_D5.1mm_W3.2mm_P5.00mm

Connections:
unnamed: C1.1, RV1.1
unnamed: C1.2, CD2.1, RSPK1.T
unnamed: C2.1, CD4.1, RMIC1.T
unnamed: C2.2, CD3.1, PCSPK1.T
unnamed: CD1.1, PCMIC1.T, RV1.2
unnamed: CD1.2, CD2.2, PCMIC1.S, RSPK1.S
unnamed: CD3.2, CD4.2, PCSPK1.S, RMIC1.S

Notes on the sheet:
[Quick TX path] Audio flows in left to right (L2R) direction
[Quick RX path] Audio flows in right to left (R2L) direction
Notes: 1. RX and TX audio interfacing is done via 3.5mm AUX audio cables. Stereo jacks + Stereo AUX cables (TRS) are fine to use. 2. CAT control is done via a separate USB cable for uBitx. NOTE: Use PC and Radio controls to adjust audio levels. 3. I have an isolated "Bourns LM-NP-1001-B1L audio tra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

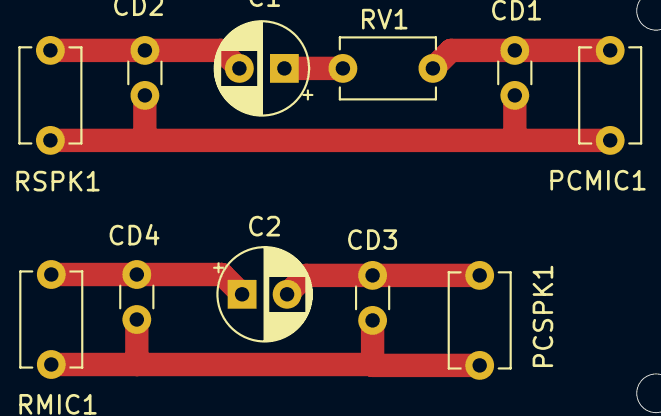
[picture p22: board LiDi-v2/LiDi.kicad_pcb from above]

Board: 2 copper layers, 11 parts (0 on the bottom side), 7 nets.
